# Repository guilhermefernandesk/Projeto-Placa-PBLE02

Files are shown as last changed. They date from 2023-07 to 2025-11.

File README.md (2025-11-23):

# Projeto-Placa-PBLE02
O projeto consiste na montagem de uma placa realizada por alunos da unifei. Bem como suas correções necessárias e simulação de uma aplicação via software na linguagem C.

## Autores:
<ul>
  <li> Eric Makiya Lazanha </li>
  <li> Guilherme Fernandes de Oliveira </li>
  <li> João Luiz de Miranda Cilli </li>
  <li> João Roberto da Silva Couto </li>
</ul>

## Imagens:
  PQDB
  PQDB2

## Vídeo apresentação do projeto:
https://drive.google.com/file/d/1amIkBEUgF5RGjeDBrGX1CGrTWx1kXM-I/view?usp=sharing

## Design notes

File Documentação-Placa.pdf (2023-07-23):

## Universidade Federal de Itajubá - UNIFEI

## PBLE02

## Board Bring-up e Validação de Protótipos Eletrônicos

Documentação do projeto

Grupo 01

Data

11/07/2023

## Sumário

IDENTIFICAÇÃO

Nome | Função | Matrícula
Eric Makiya Lazanha | Documentação | 2022004565
Guilherme Fernandes de Oliveira | Hardware | 2021005067
João Luiz de Miranda Cilli | Software | 2022003942
João Roberto da Silva Couto | Hardware | 2018000944

INTRODUÇÃO

Este documento tem como objetivo analisar os erros e fazer as mudanças necessárias para o funcionamento do projeto eletrônico desenvolvido pelo grupo 01 da disciplina Co-Design de Produtos Eletrônicos (PBLE01). Aqui encontram-se registrados os requisitos do hardware, com seus esquemas elétricos e layout de placa comentados de acordo com as modificações requeridas. Além disso, este documento apresenta diagramas para facilitar a compreensão da programação utilizada no projeto.

REQUISITOS DE DESENVOLVIMENTO

Divisões dos requisitos | Requisitos
Requisitos de alimentação | Suportar tensão de entrada na faixa de 7V a 12V em corrente contínua.

Empregar um conector de alimentação do tipo Jack J4.

Empregar proteção contra tensão reversa (opcional).

Empregar um regulador linear com saída de 5V.

Empregar um diodo emissor de luz para sinalizar a

presença de alimentação na placa.

Requisitos de

processamento

Empregar microcontrolador PIC18F4550 como unidade

de processamento e controle.

Possuir uma barra de pinos compatível com o padrão de

gravação ICSP para o microcontrolador empregado.

Possuir uma chave táctil para reiniciar a operação do

microcontrolador.

Requisitos de interações

com o usuário

Possuir um teclado numérico de cinco (5) teclas

confeccionado a partir de chaves tácteis.

Possuir um visor de 16x2 caracteres da família JHD62A,

com luminosidade a ser controlada por meio de

potenciômetro.

Possuir conjunto de, pelo menos, quatro (4) diodos

emissores de luz (LED) a partir do qual seja possível

sinalizar estados diversos de operação da unidade de

processamento e controle.

Possuir um potenciômetro (tripot) com o qual permitir a

entrada de valores contínuos por parte dos usuários.

Requisitos de periféricos e

expansão

Empregar um relógio de tempo real da família MCP7940.

Possuir uma barra de expansão que contemple os sinais

de referência e de alimentação da placa e quatro entradas

analógicas a formarem dois pares de entradas analógicas

diferenciais. Tais pares devem ser condicionados de

forma a se gerar níveis entre 0V e 3V a serem

disponibilizados ao microcontrolador empregado.

Possuir uma saída analógica formada por sinal em

modulação PWM.

Possuir uma barra de expansão de sinais que contemple

os sinais de referência (terra) e de alimentação do circuito

assim como os demais pinos não utilizados do

microcontrolador.

Requisitos adicionais

Empregar um conversor USB-serial da família MCP2200

que permita comunicação | serial | com | a placa

desenvolvida.

CIRCUITO

Para a melhor organização do esquemático, foram criados sub-circuitos, unidos por meio de rótulos hierárquicos. Os 4 sub circuitos são: Alimentação, Operação, Periféricos e Expansão, Interação com o usuário, assim como mostra a figura abaixo:

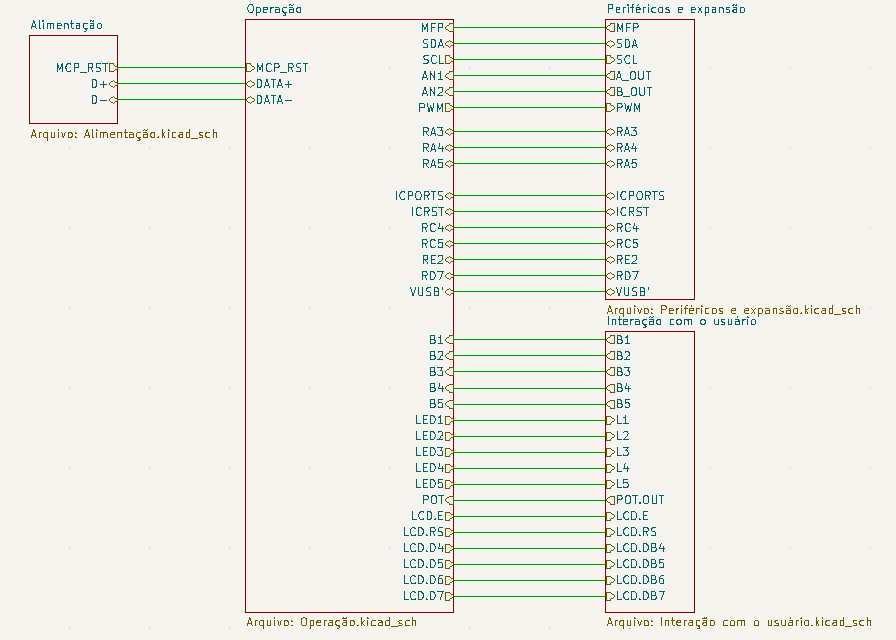
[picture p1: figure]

Figura 1 Blocos funcionais

CORREÇÕES DE HARDWARE
CIRCUITO DE OPERAÇÕES

Mudanças para o funcionamento do sub-circuito de Alimentação.

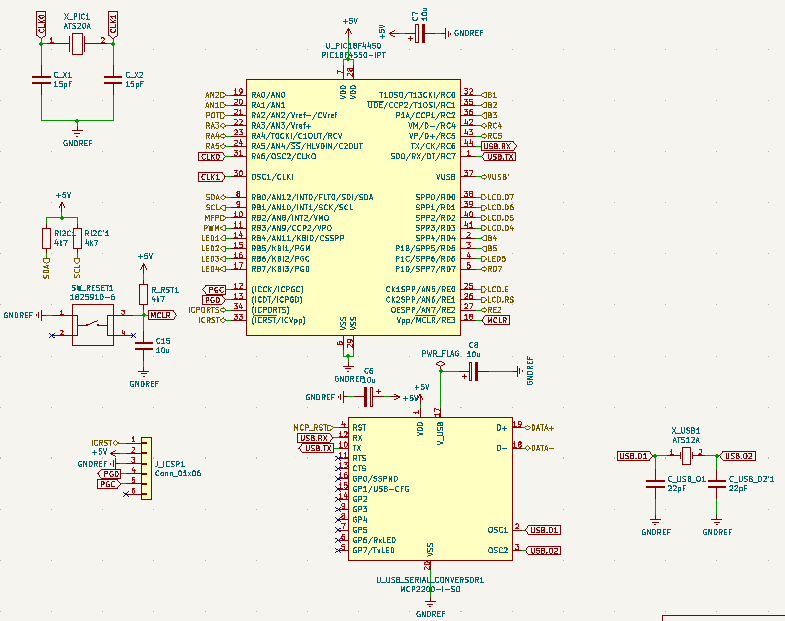
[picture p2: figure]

Figura 2 Sub-circuito de Alimentação completo corrigido

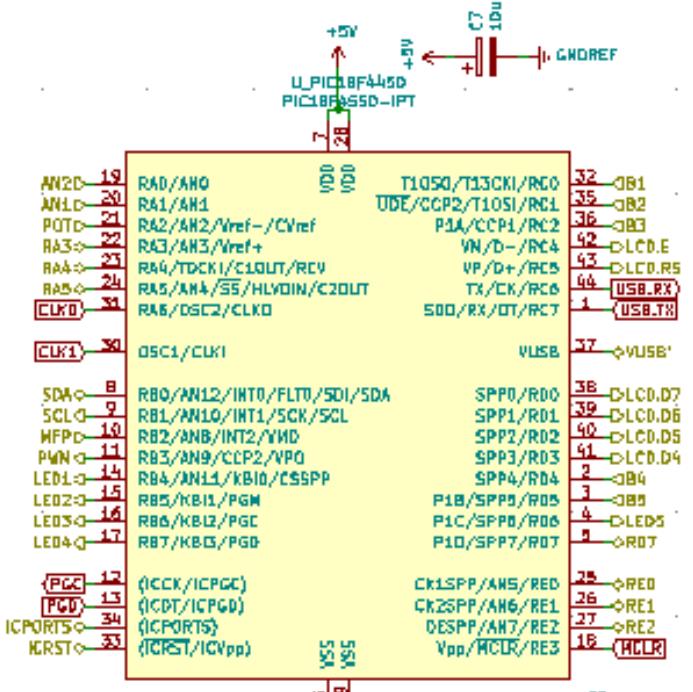
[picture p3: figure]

Figura 3 PIC18F4550 sem as alterações

O PGC e PGD não foram ligados aos pinos recomendados pelo fabricante, a recomendação é utilizar o PGC ligado ao pino 16 e o PGD ao pino 17. Como eles foram conectados a pinos diferentes algumas mudanças foram necessárias.

Tabela 1 informações da página 313 do datasheet do pic18f4550

Dessa forma, foi necessário fazer alterações envolvendo os pinos 18 e 33, o 18 (MCLR), originalmente ia para o pino 1 do conector de gravação do PICkit (PPTC061LFBN-RC), foi conectado ao botão de reset e o 33 (ICRST), que estava no sétimo pino de expansão, foi direcionado ao lugar anteriormente ocupado pelo MCLR no pino 1 do conector de gravação do PICkit. O MCLR atuava como um pino secundário (legacy), foi preciso passar para um pino com prioridade ICRST (dedicated).

O pino 18 (MCLR) do PIC18F4550 foi cortado de sua trilha original e passa direto para o botão de reset.

Observação: Reset deve ficar em nível lógico alto.

Figura 4 Esquemático antes

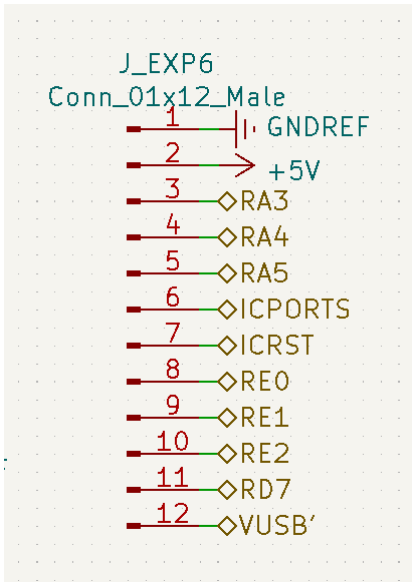
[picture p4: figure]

Figura 5 Pino de expansão antes

Pino 33 (ICRST) foi direcionado ao lugar anteriormente ocupado pelo MCLR no PPTC061LFBN-RC

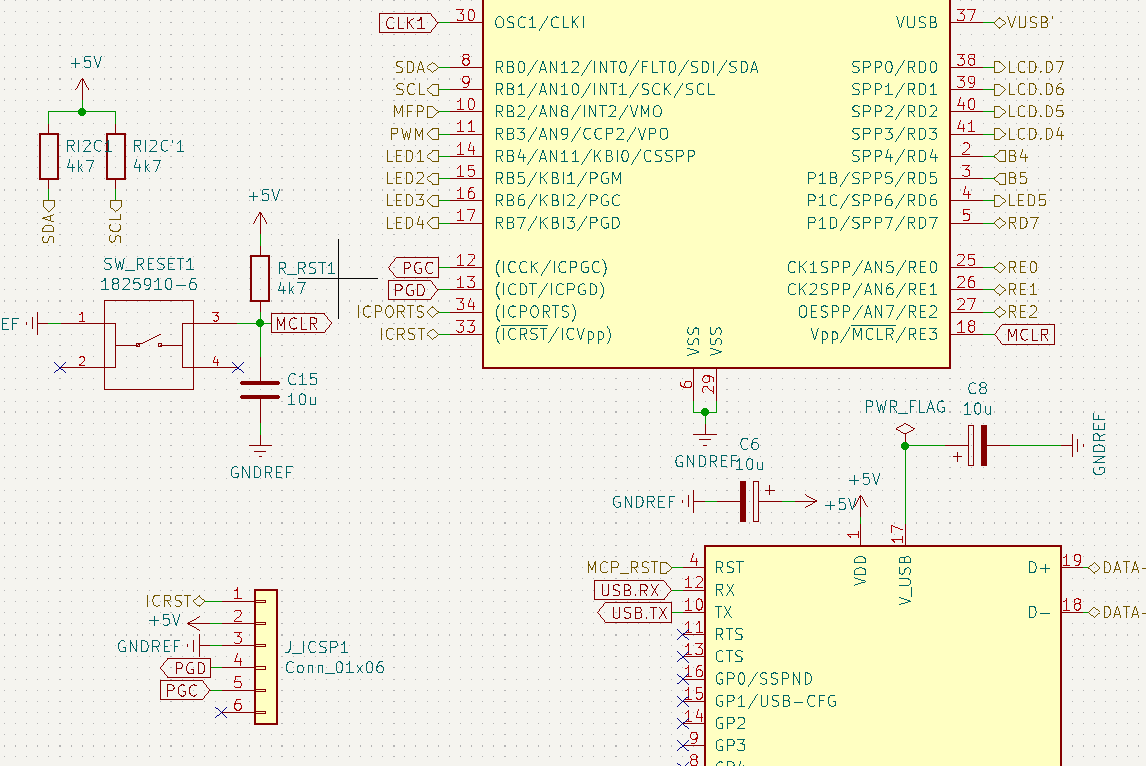
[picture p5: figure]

Figura 6 Correção ICRST e MCLR

Pino 33 (ICRST) foi retirado do header de expansão.

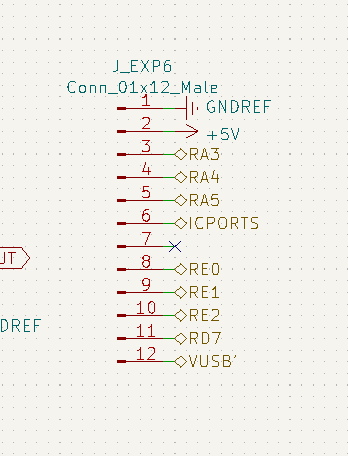
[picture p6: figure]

Figura 7 Pino de expansão depois

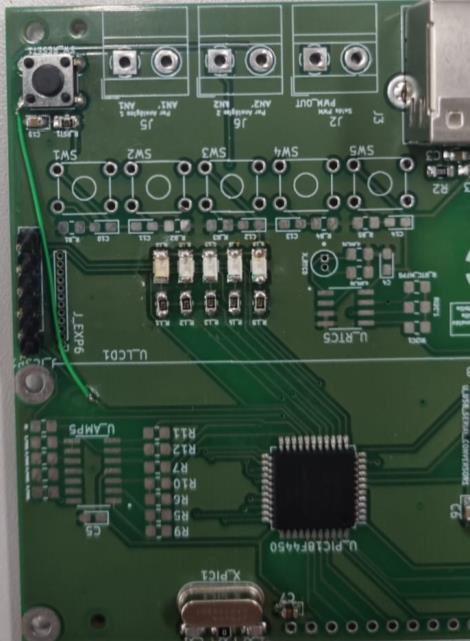
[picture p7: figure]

Figura 8 Redirecionamento do pino 18

O pino 33 (ICRST) foi ligado ao PPTC061LFBN-RC onde estava o MCLR.

Figura 9 Ajuste do ICRST

O pino 15 (LED2) do display estava no GND foi necessário colocá-lo no VCC. Pois a iluminação estava baixa.

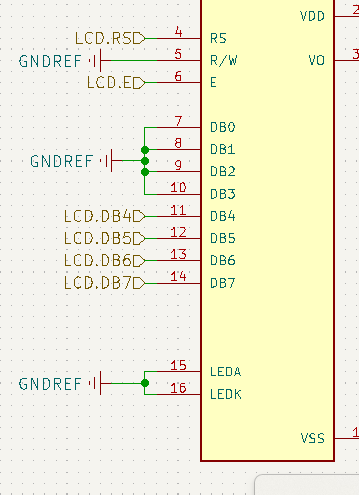
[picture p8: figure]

Figura 10 Esquemático antes

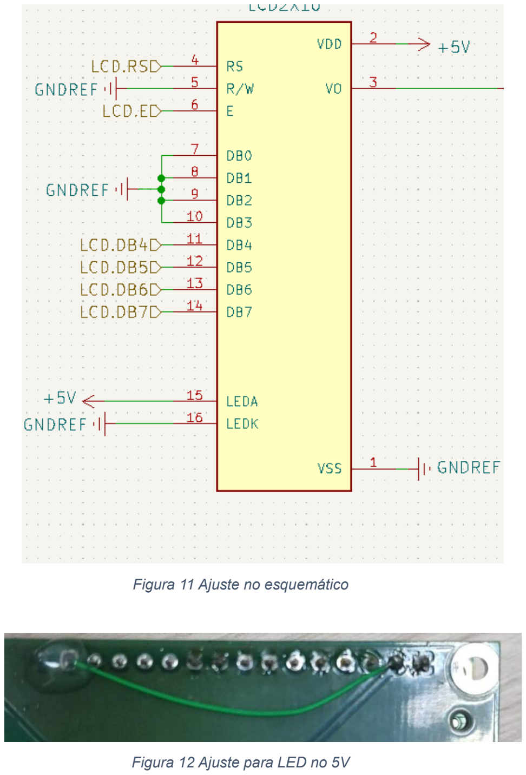
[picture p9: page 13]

Figura 11 Ajuste no esquemático

Figura 12 Ajuste para LED no 5V

Os pinos 42 (RC4) e 43 (RC5) que fazem a ligação com os displays não podem atuar como saídas, portanto tiveram que ser alterados. Dessa forma, optou-se por utilizar os pinos de expansão, trocando o pino 42 pelo 25 (8 da expansão) e o pino 43 pelo 26 (9 da expansão).

Figura 13 Esquemático antes

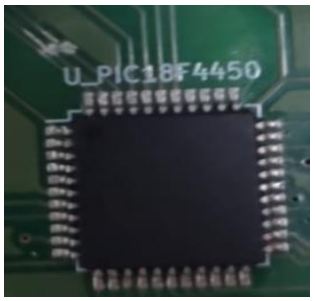
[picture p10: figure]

Figura 14 Corte das trilhas dos pinos 42 e 43

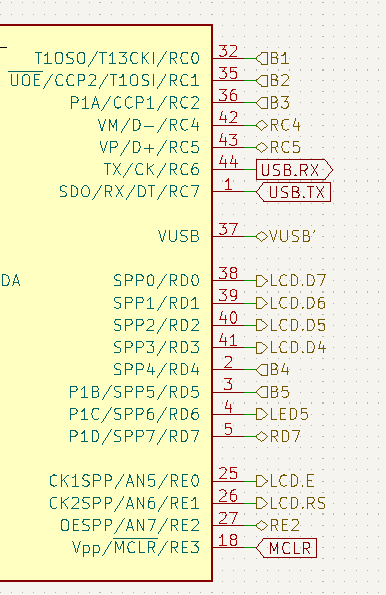
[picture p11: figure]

Figura 15 Esquemático corrigido

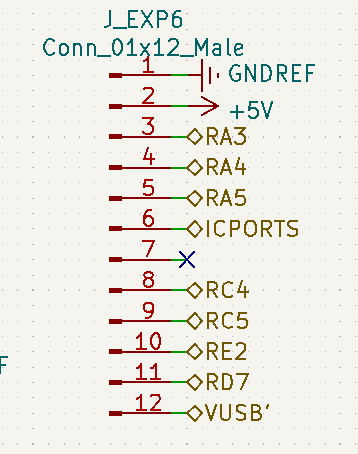
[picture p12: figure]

Figura 16 LEDs nos pinos de expansão 8 e 9

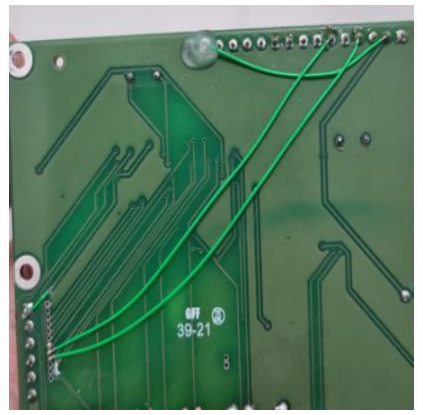
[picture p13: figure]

Figura 17 justes para os pinos de expansão

Foram trocados os capacitores do micro para um capacitor de 18pF em paralelo com um capacitor de 18pF (18pF em série com um resistor de 0 ohms), o datasheet recomendava dois capacitores de 15pF em paralelo.

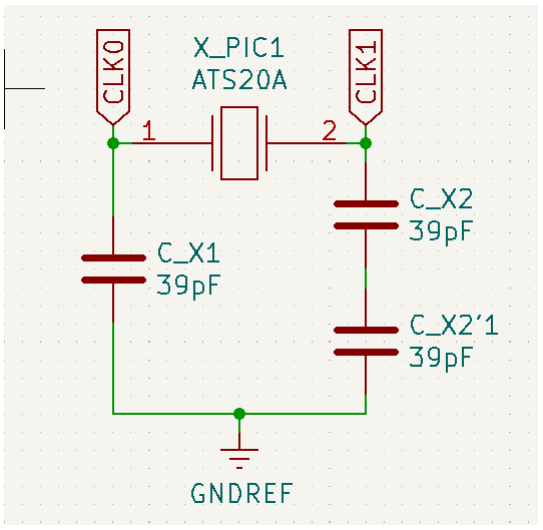
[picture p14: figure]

Figura 18 Esquemático cristal antes

Figura 19 Ajuste para capacitores de 15pF em paralelo

Foram trocados os capacitores do usb para um capacitor de 22pF em paralelo com um capacitor de 22pF (22pF em série com um resistor de 0 ohms), conforme o datasheet recomenda.

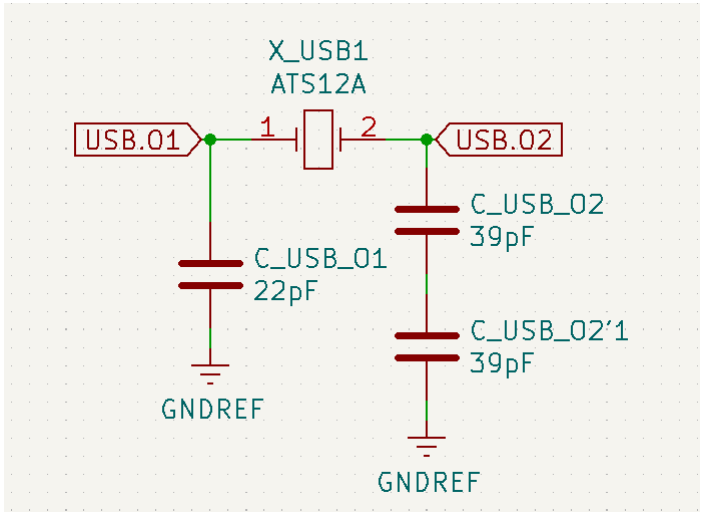
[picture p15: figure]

Figura 20 Capacitores do usb antes

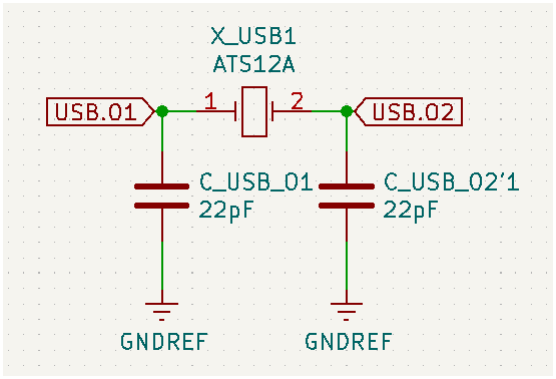
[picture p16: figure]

Figura 21 Capacitores usb corrigidos

CIRCUITO DE INTERAÇÃO COM O USUÁRIO

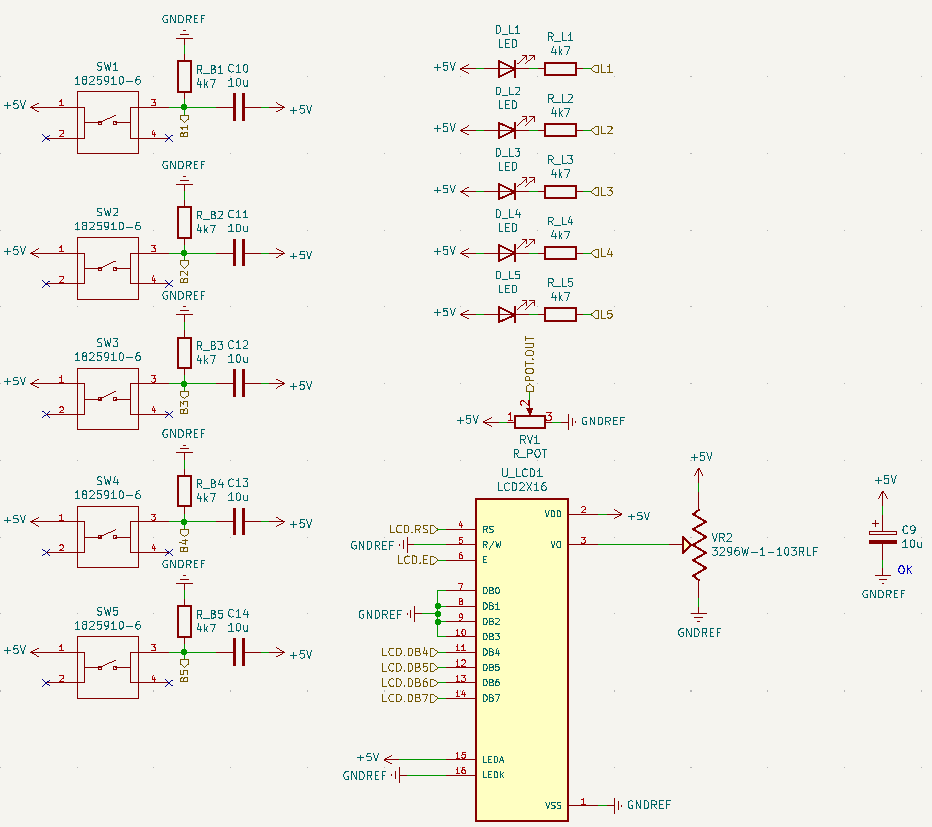
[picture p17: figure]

Figura 22 Sub-circuito de Interação com o usuário completo corrigido

Todos os resistores de 330 Ohms foral substituídos por resistores de 4k7 Ohms para ajuste da intensidade de brilho.

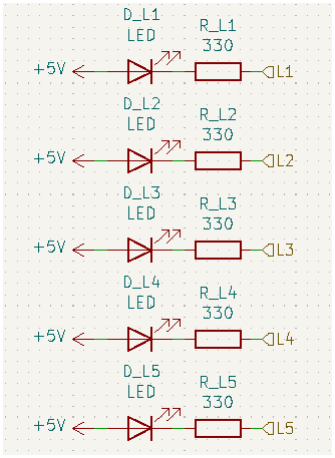
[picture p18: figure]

Figura 23 Esquemático antes da correção

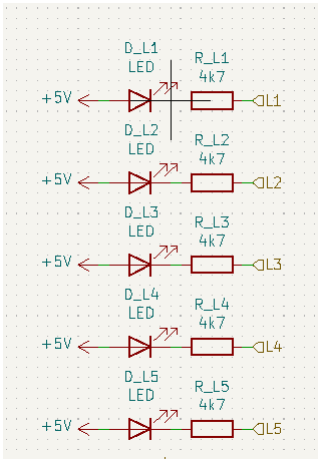
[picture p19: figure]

Figura 24 Resistores corrigidos

Foi necessário ajustar o header para 90° para o encaixe simultâneo do PICkit com o display. Anteriormente o display ficava sobre o PICkit, impedindo o encaixe.

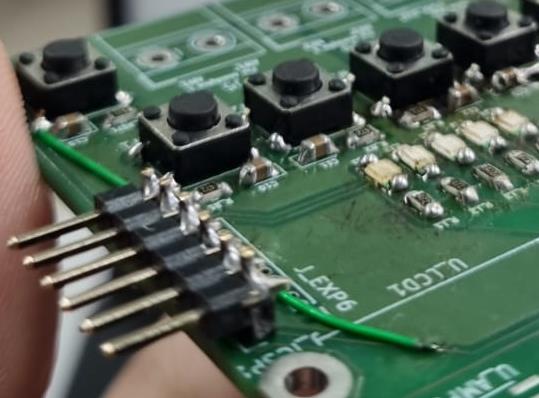
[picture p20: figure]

Figura 25 Header 90°

Figura 26 PICkit e display

PCB

Figura 27 PCB completa corrigida

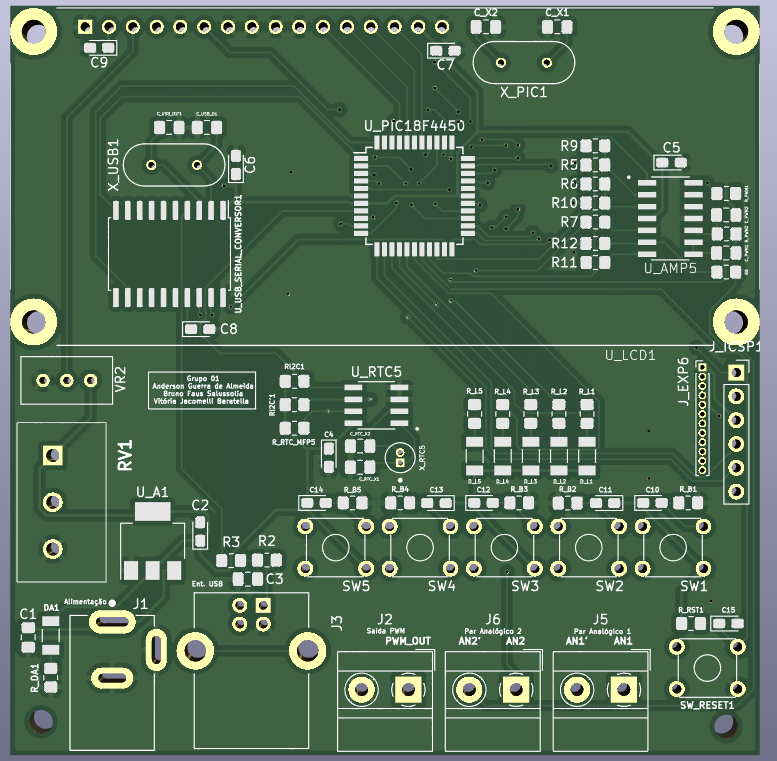
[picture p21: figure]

Figura 28 Visão frontal 3D

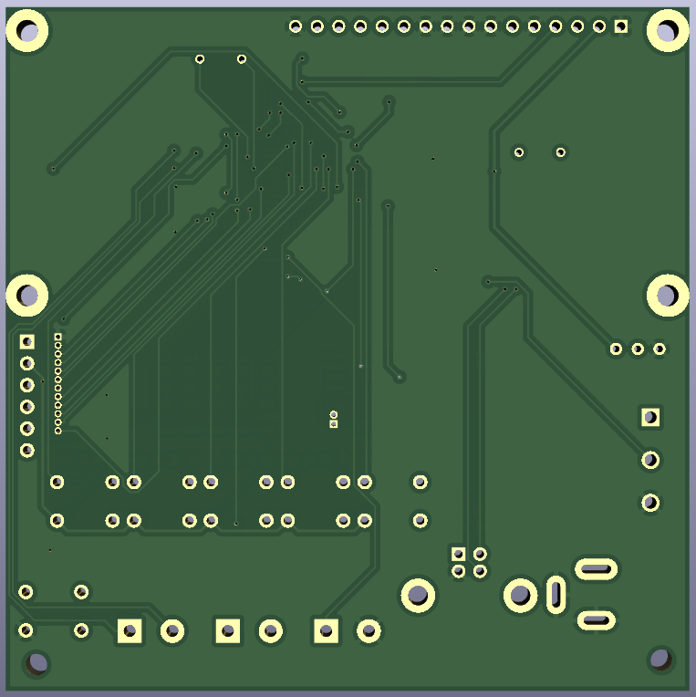
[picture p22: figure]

Figura 29 Visão de trás

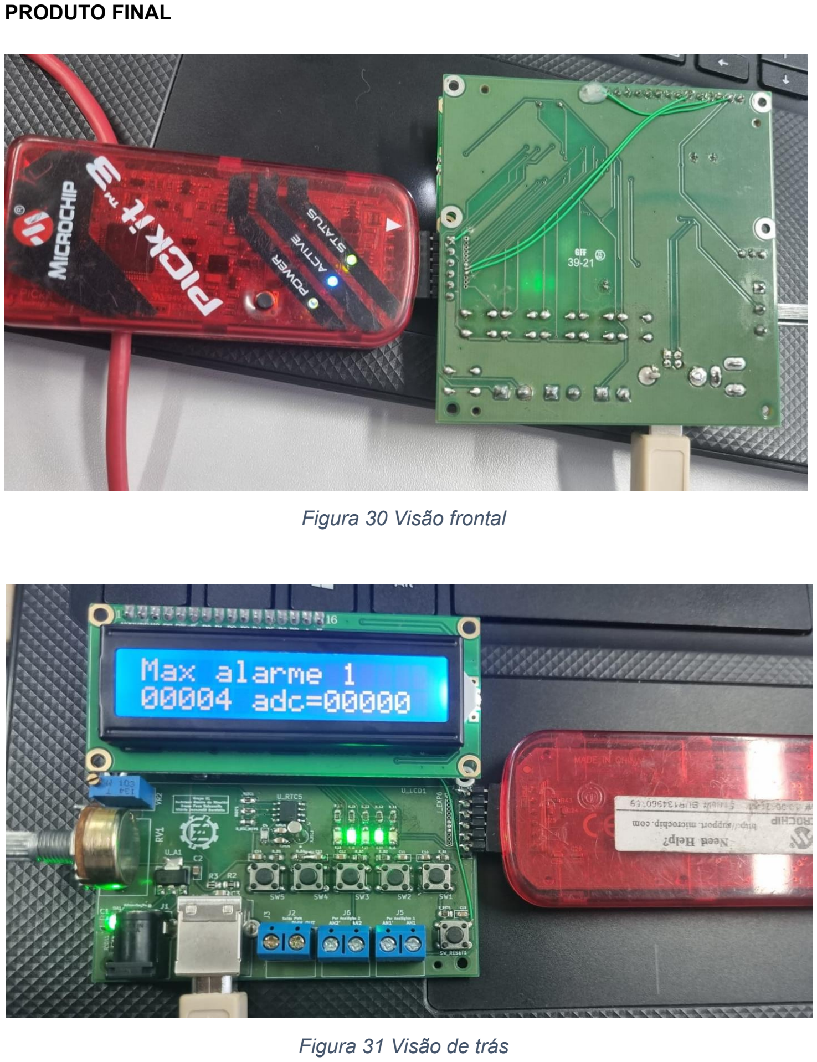
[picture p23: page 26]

PRODUTO FINAL

Figura 30 Visão frontal

Figura 31 Visão de trás

DIAGRAMAS

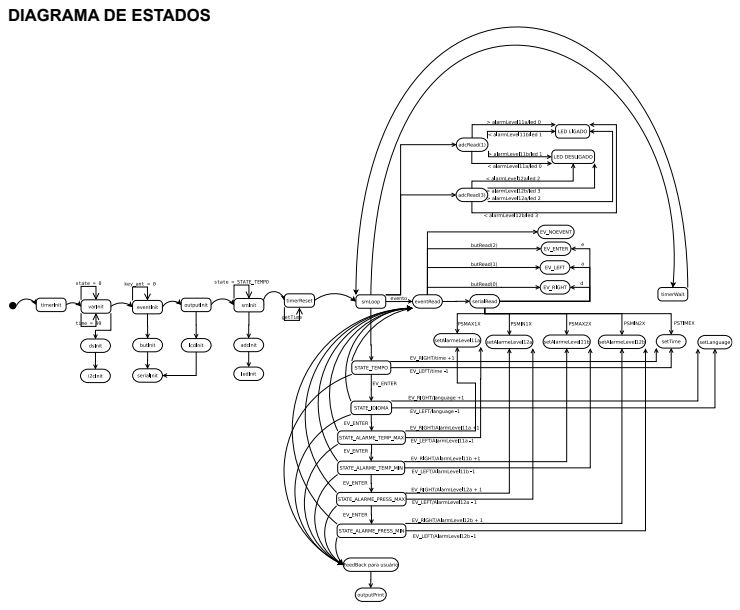
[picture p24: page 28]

DIAGRAMA DE ESTADOS

BIBLIOGRAFIA

[1] LD1117DT50TR. Datasheet: https://br.mouser.com/datasheet/2/389/cd00000544-1795431.pdf (https://br.mouser.com/datasheet/2/389/cd00000544-1795431.pdf)
[2] PIC18F4550-I/PT. Datasheet: https://www.mouser.com/datasheet/2/268/39632e-48732.pdf (https://www.mouser.com/datasheet/2/268/39632e-48732.pdf)
[3] LD1117DT50TR. Datasheet: https://br.mouser.com/datasheet/2/389/cd00000544-1795431.pdf (https://br.mouser.com/datasheet/2/389/cd00000544-1795431.pdf)
[4] MCP7940N-I/SN. Datasheet: https://br.mouser.com/datasheet/2/268/25010A-71550.pdf
[5] MCP2200-I/SO. Datasheet: https://www.maxwell.vrac.puc-rio.br/11319/11319_8.PDF
[6] PJ-002A. Datasheet: https://br.mouser.com/datasheet/2/670/pj_002a-1778764.pdf
[7] LTST-C150GKT. Datasheet:

https://datasheet.datasheetarchive.com/originals/dk/DKDS-9/177278.pdf

[8] PPTC061LFBN-RC. Datasheet: https://www.digikey.com/en/products/detail/sullins-

connector- (https://www.digikey.com/en/products/detail/sullins-connector-solutions/PPTC061LFBN-RC/810145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) solutions/PPTC061LFBN-

RC/810145?utm_campaign=buynow&utm_medium=aggregator&WT.z_cid=ref_findchips_standard

&utm_sou (https://www.digikey.com/en/products/detail/sullins-connector-solutions/PPTC061LFBN-RC/810145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) rce=findchips (https://www.digikey.com/en/products/detail/sullins-connector-solutions/PPTC061LFBN-RC/810145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)

[9] 1825910-6. Datasheet:

https://www.te.com/commerce/DocumentDelivery/DDEController?Action=srchrtrv&Doc

Nm=1825 (https://www.te.com/commerce/DocumentDelivery/DDEController?Action=srchrtrv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) 910&DocType=Customer+Drawing&DocLang=English&PartCntxt=1825910-

6&DocFormat=pdf (https://www.te.com/commerce/DocumentDelivery/DDEController?Action=srchrtrv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)
[10] LM358DG / LM324DG. Datasheet:

https://br.mouser.com/datasheet/2/308/1/LM324_D-2314880.pdf
[11] JHD162A. Datasheet:

https://www.alldatasheet.com/datasheet-

pdf/pdf/127934/ETC1/JHD162A.html (https://www.alldatasheet.com/datasheet-pdf/pdf/127934/ETC1/JHD162A.html)
[12] P160KN-0QC15B100K. Datasheet: https://br.mouser.com/datasheet/2/414/P160-1545428.pdf (https://br.mouser.com/datasheet/2/414/P160-1545428.pdf)
[13] 897-43-004-90-000000. Datasheet: https://www.mouser.com/datasheet/2/273/148-259756.pdf (https://www.mouser.com/datasheet/2/273/148-259756.pdf)
[14] F931C106KAA. Datasheet: https://br.mouser.com/datasheet/2/40/f93-776559.pdf
[15] AB38T-32. Datasheet: https://html.alldatasheet.com/htmlpdf/563572/ABRACON/AB38T-32-

ATS20A 768KHZ/610/2/AB38T-32-768KHZ.html (https://html.alldatasheet.com/html-pdf/563572/ABRACON/AB38T-32-ATS20A%20768KHZ/610/2/AB38T-32-768KHZ.html)

[16] ATS20A. Datasheet: https://br.mouser.com/datasheet/2/96/008-0309-0-786275.pdf
[17] 1N4001RLG. Datasheet: https://dir.heisener.com/specification-pdf/en/1N4001RLG.pdf
[18] 1N5819HW-7. Datasheet: https://br.mouser.com/datasheet/2/115/ds30217-71027.pdf
[19] Henrique Mattede. Mundo da Elétrica. Disponível em: <

https://www.mundodaele- (https://www.mundodaeletrica.com.br/aprenda-como-calcular-resistor-para-led/) trica.com.br/aprenda-como-calcular-resistor-para-

led/ (https://www.mundodaeletrica.com.br/aprenda-como-calcular-resistor-para-led/) >. Acesso em 20 de maio de 2021.
[20] Ronieri Rezende. Embarcados. Disponível em: <

https://www.embarcados.com.br/interface-gra-fica-para-uart/ >. Acesso em 8 de ago. de

2021

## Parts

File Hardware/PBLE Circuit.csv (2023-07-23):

Source: | C:\Users\ericl\OneDrive\Área de Trabalho\Faculdade\PLBE02\PBLE Circuit-20230606T190801Z-001\PBLE Circuit\PBLE Circuit.kicad_sch
Date: | 06/06/2023 16:24:42
Tool: | Eeschema (6.0.4)
Generator: | C:\Program Files\KiCad\6.0\bin\scripting\plugins/bom_csv_grouped_by_value.py
Component Count: | 82
Individual Components:
Item | Qty | Reference(s) | Value | LibPart | Footprint | Datasheet | Comment | Configuration_Pole-Throw | Contact_Current_Rating | EU_RoHS_Compliance | MANUFACTURER | MAXIMUM_PACKAGE_HIEGHT | PARTREV | STANDARD
 |  | C1 | 100n | Device:C | Capacitor_SMD:C_0805_2012Metric_Pad1.18x1.45mm_HandSolder | ~
 |  | C2 | 10u | PBLE-Circuit-rescue:CP-Device | Capacitor_Tantalum_SMD:CP_EIA-2012-15_AVX-P_Pad1.30x1.05mm_HandSolder
 |  | C3 | 100nF | Device:C | Capacitor_SMD:C_0805_2012Metric_Pad1.18x1.45mm_HandSolder | ~
 |  | C4 | 10u | PBLE-Circuit-rescue:CP-Device | Capacitor_Tantalum_SMD:CP_EIA-2012-15_AVX-P_Pad1.30x1.05mm_HandSolder
 |  | C5 | 10u | PBLE-Circuit-rescue:CP-Device | Capacitor_Tantalum_SMD:CP_EIA-2012-15_AVX-P_Pad1.30x1.05mm_HandSolder
 |  | C6 | 10u | PBLE-Circuit-rescue:CP-Device | Capacitor_Tantalum_SMD:CP_EIA-2012-15_AVX-P_Pad1.30x1.05mm_HandSolder
 |  | C7 | 10u | PBLE-Circuit-rescue:CP-Device | Capacitor_Tantalum_SMD:CP_EIA-2012-15_AVX-P_Pad1.30x1.05mm_HandSolder
 |  | C8 | 10u | PBLE-Circuit-rescue:CP-Device | Capacitor_Tantalum_SMD:CP_EIA-2012-15_AVX-P_Pad1.30x1.05mm_HandSolder
 |  | C9 | 10u | PBLE-Circuit-rescue:CP-Device | Capacitor_Tantalum_SMD:CP_EIA-2012-15_AVX-P_Pad1.30x1.05mm_HandSolder
 |  | C10 | 10u | Device:C | Capacitor_Tantalum_SMD:CP_EIA-2012-15_AVX-P_Pad1.30x1.05mm_HandSolder | ~
 |  | C11 | 10u | Device:C | Capacitor_Tantalum_SMD:CP_EIA-2012-15_AVX-P_Pad1.30x1.05mm_HandSolder | ~
 |  | C12 | 10u | Device:C | Capacitor_Tantalum_SMD:CP_EIA-2012-15_AVX-P_Pad1.30x1.05mm_HandSolder | ~
 |  | C13 | 10u | Device:C | Capacitor_Tantalum_SMD:CP_EIA-2012-15_AVX-P_Pad1.30x1.05mm_HandSolder | ~
 |  | C14 | 10u | Device:C | Capacitor_Tantalum_SMD:CP_EIA-2012-15_AVX-P_Pad1.30x1.05mm_HandSolder | ~
 |  | C15 | 10u | Device:C | Capacitor_Tantalum_SMD:CP_EIA-2012-15_AVX-P_Pad1.30x1.05mm_HandSolder | ~
 |  | C_PWM1 | 20p | Device:C | Capacitor_SMD:C_0805_2012Metric_Pad1.18x1.45mm_HandSolder | ~
 |  | C_PWM2 | 39p | Device:C | Capacitor_SMD:C_0805_2012Metric_Pad1.18x1.45mm_HandSolder | ~
 |  | C_RTC_X1 | 22pF | Device:C | Capacitor_SMD:C_0805_2012Metric_Pad1.18x1.45mm_HandSolder | ~
 |  | C_RTC_X2 | 22pF | Device:C | Capacitor_SMD:C_0805_2012Metric_Pad1.18x1.45mm_HandSolder | ~
 |  | C_USB_O1 | 22pF | Device:C | Capacitor_SMD:C_0805_2012Metric_Pad1.18x1.45mm_HandSolder | ~
 |  | C_USB_O2 | 39pF | Device:C | Capacitor_SMD:C_0805_2012Metric_Pad1.18x1.45mm_HandSolder | ~
 |  | C_USB_O2'1 | 39pF | Device:C | Capacitor_SMD:C_0805_2012Metric_Pad1.18x1.45mm_HandSolder | ~
 |  | C_X1 | 39pF | Device:C | Capacitor_SMD:C_0805_2012Metric_Pad1.18x1.45mm_HandSolder | ~
 |  | C_X2 | 39pF | Device:C | Capacitor_SMD:C_0805_2012Metric_Pad1.18x1.45mm_HandSolder | ~
 |  | C_X2'1 | 39pF | Device:C | Capacitor_SMD:C_0805_2012Metric_Pad1.18x1.45mm_HandSolder | ~
 |  | D_L1 | LED | Device:LED | Biblioteca PCB:LTST-C150GKT | ~
 |  | D_L2 | LED | Device:LED | Biblioteca PCB:LTST-C150GKT | ~
 |  | D_L3 | LED | Device:LED | Biblioteca PCB:LTST-C150GKT | ~
 |  | D_L4 | LED | Device:LED | Biblioteca PCB:LTST-C150GKT | ~
 |  | D_L5 | LED | Device:LED | Biblioteca PCB:LTST-C150GKT | ~
 |  | DA1 | LED | Device:LED | Biblioteca PCB:LTST-C150GKT | ~
 |  | J1 | PJ-002A | PBLE Library:PJ-002A | Biblioteca PCB:CUI_PJ-002A |  |  |  |  |  | CUI INC |  |  | Manufacturer recommendations
 |  | J2 | Screw_Terminal_01x02 | Connector:Screw_Terminal_01x02 | TerminalBlock_MetzConnect:TerminalBlock_MetzConnect_Type011_RT05502HBWC_1x02_P5.00mm_Horizontal | ~
 |  | J3 | USB_B | Connector:USB_B | Connector_USB:USB_B_Lumberg_2411_02_Horizontal | ~
 |  | J5 | Screw_Terminal_01x02 | Connector:Screw_Terminal_01x02 | TerminalBlock_MetzConnect:TerminalBlock_MetzConnect_Type011_RT05502HBWC_1x02_P5.00mm_Horizontal | ~
 |  | J6 | Screw_Terminal_01x02 | Connector:Screw_Terminal_01x02 | TerminalBlock_MetzConnect:TerminalBlock_MetzConnect_Type011_RT05502HBWC_1x02_P5.00mm_Horizontal | ~
 |  | J_EXP6 | Conn_01x12_Male | Connector:Conn_01x12_Male | Connector_PinHeader_1.00mm:PinHeader_1x12_P1.00mm_Vertical | ~
 |  | J_ICSP1 | Conn_01x06 | Connector_Generic:Conn_01x06 | Connector_PinSocket_2.54mm:PinSocket_1x06_P2.54mm_Vertical | ~
 |  | R2 | 10k | Device:R | Resistor_SMD:R_0805_2012Metric_Pad1.20x1.40mm_HandSolder | ~
 |  | R3 | 470 | Device:R | Resistor_SMD:R_0805_2012Metric_Pad1.20x1.40mm_HandSolder | ~
 |  | R5 | 10k | Device:R | Resistor_SMD:R_0805_2012Metric_Pad1.20x1.40mm_HandSolder | ~
 |  | R6 | 10k | Device:R | Resistor_SMD:R_0805_2012Metric_Pad1.20x1.40mm_HandSolder | ~
 |  | R7 | 10k | Device:R | Resistor_SMD:R_0805_2012Metric_Pad1.20x1.40mm_HandSolder | ~
 |  | R8 | 10k | Device:R | Resistor_SMD:R_0805_2012Metric_Pad1.20x1.40mm_HandSolder | ~
 |  | R9 | 2k4 | Device:R | Resistor_SMD:R_0805_2012Metric_Pad1.20x1.40mm_HandSolder | ~
 |  | R10 | 2k4 | Device:R | Resistor_SMD:R_0805_2012Metric_Pad1.20x1.40mm_HandSolder | ~
 |  | R11 | 2k4 | Device:R | Resistor_SMD:R_0805_2012Metric_Pad1.20x1.40mm_HandSolder | ~
 |  | R12 | 2k4 | Device:R | Resistor_SMD:R_0805_2012Metric_Pad1.20x1.40mm_HandSolder | ~
 |  | R_B1 | 4k7 | Device:R | Resistor_SMD:R_0805_2012Metric_Pad1.20x1.40mm_HandSolder | ~
 |  | R_B2 | 4k7 | Device:R | Resistor_SMD:R_0805_2012Metric_Pad1.20x1.40mm_HandSolder | ~
 |  | R_B3 | 4k7 | Device:R | Resistor_SMD:R_0805_2012Metric_Pad1.20x1.40mm_HandSolder | ~
 |  | R_B4 | 4k7 | Device:R | Resistor_SMD:R_0805_2012Metric_Pad1.20x1.40mm_HandSolder | ~
 |  | R_B5 | 4k7 | Device:R | Resistor_SMD:R_0805_2012Metric_Pad1.20x1.40mm_HandSolder | ~
 |  | R_DA1 | 330 | Device:R | Resistor_SMD:R_0805_2012Metric_Pad1.20x1.40mm_HandSolder | ~
 |  | R_L1 | 330 | Device:R | Resistor_SMD:R_0805_2012Metric_Pad1.20x1.40mm_HandSolder | ~
 |  | R_L2 | 330 | Device:R | Resistor_SMD:R_0805_2012Metric_Pad1.20x1.40mm_HandSolder | ~
 |  | R_L3 | 330 | Device:R | Resistor_SMD:R_0805_2012Metric_Pad1.20x1.40mm_HandSolder | ~
 |  | R_L4 | 330 | Device:R | Resistor_SMD:R_0805_2012Metric_Pad1.20x1.40mm_HandSolder | ~
 |  | R_L5 | 330 | Device:R | Resistor_SMD:R_0805_2012Metric_Pad1.20x1.40mm_HandSolder | ~
 |  | R_PWM1 | 20k | Device:R | Resistor_SMD:R_0805_2012Metric_Pad1.20x1.40mm_HandSolder | ~
 |  | R_PWM2 | 20k | Device:R | Resistor_SMD:R_0805_2012Metric_Pad1.20x1.40mm_HandSolder | ~
 |  | R_RST1 | 4k7 | Device:R | Resistor_SMD:R_0805_2012Metric_Pad1.20x1.40mm_HandSolder | ~
 |  | R_RTC_MFP5 | 10k | Device:R | Resistor_SMD:R_0805_2012Metric_Pad1.20x1.40mm_HandSolder | ~
 |  | RI2C1 | 4k7 | Device:R | Resistor_SMD:R_0805_2012Metric_Pad1.20x1.40mm_HandSolder | ~
 |  | RI2C'1 | 4k7 | Device:R | Resistor_SMD:R_0805_2012Metric_Pad1.20x1.40mm_HandSolder | ~
 |  | RV1 | R_POT | PBLE-Circuit-rescue:R_POT-Device | Biblioteca PCB:P160KN-0QC15B100K
 |  | SW1 | 1825910-6 | PBLE Library:1825910-6 | Button_Switch_THT:SW_TH_Tactile_Omron_B3F-10xx |  | 1825910-6 | Single Pole - Single Throw | 50 mA | Compliant
 |  | SW2 | 1825910-6 | PBLE Library:1825910-6 | Button_Switch_THT:SW_TH_Tactile_Omron_B3F-10xx |  | 1825910-6 | Single Pole - Single Throw | 50 mA | Compliant
 |  | SW3 | 1825910-6 | PBLE Library:1825910-6 | Button_Switch_THT:SW_TH_Tactile_Omron_B3F-10xx |  | 1825910-6 | Single Pole - Single Throw | 50 mA | Compliant
 |  | SW4 | 1825910-6 | PBLE Library:1825910-6 | Button_Switch_THT:SW_TH_Tactile_Omron_B3F-10xx |  | 1825910-6 | Single Pole - Single Throw | 50 mA | Compliant
 |  | SW5 | 1825910-6 | PBLE Library:1825910-6 | Button_Switch_THT:SW_TH_Tactile_Omron_B3F-10xx |  | 1825910-6 | Single Pole - Single Throw | 50 mA | Compliant
 |  | SW_RESET1 | 1825910-6 | PBLE Library:1825910-6 | Button_Switch_THT:SW_TH_Tactile_Omron_B3F-10xx |  | 1825910-6 | Single Pole - Single Throw | 50 mA | Compliant
 |  | U_A1 | LD1117S50TR_SOT223 | Regulator_Linear:LD1117S50TR_SOT223 | Package_TO_SOT_SMD:SOT-223-3_TabPin2 | http://www.st.com/st-web-ui/static/active/en/resource/technical/document/datasheet/CD00000544.pdf
 |  | U_AMP5 | LM324DG | PBLE Library:LM324DG | Biblioteca PCB:LM324DG
 |  | U_LCD1 | LCD2X16 | PBLE Library:LCD2X16 | Biblioteca PCB:JHD162A |  |  |  |  |  | Microelektronika | 10mm | 0 | Manufacturer Recommendations
 |  | U_PIC18F4450 | PIC18F4550-IPT | MCU_Microchip_PIC18:PIC18F4550-IPT | Package_QFP:TQFP-44_10x10mm_P0.8mm | http://ww1.microchip.com/downloads/en/DeviceDoc/39760d.pdf
 |  | U_RTC5 | MCP7940N-xSN | PBLE-Circuit-rescue:MCP7940N-xSN-Timer | Biblioteca PCB:MCP7940N | http://ww1.microchip.com/downloads/en/DeviceDoc/20005010F.pdf
 |  | U_USB_SERIAL_CONVERSOR1 | MCP2200-I-SO | Interface_USB:MCP2200-I-SO | Package_SO:SOIC-20W_7.5x12.8mm_P1.27mm | http://ww1.microchip.com/downloads/en/DeviceDoc/200022228D.pdf
 |  | VR2 | 3296W-1-103RLF | PBLE Library:3296W-1-103RLF | Potentiometer_THT:Potentiometer_Bourns_3296W_Vertical |  |  |  |  |  | Bourns |  | 05/16 | Manufacturer Recommendation
 |  | X_PIC1 | ATS20A | PBLE Library:ATS20A | Biblioteca PCB:ATS20A
 |  | X_RTC5 | AB38T-32.768KHZ | PBLE Library:AB38T-32.768KHZ | Biblioteca PCB:AB38T |  |  |  |  |  | Abracon Corparation |  | 12.29.14 | IPC-7251
 |  | X_USB1 | ATS12A | PBLE Library:ATS12A | Biblioteca PCB:ATS12A
Collated Components:
Item | Qty | Reference(s) | Value | LibPart | Footprint | Datasheet | Comment | Configuration_Pole-Throw | Contact_Current_Rating | EU_RoHS_Compliance | MANUFACTURER | MAXIMUM_PACKAGE_HIEGHT | PARTREV | STANDARD
1 | 1 | C1 | 100n | Device:C | Capacitor_SMD:C_0805_2012Metric_Pad1.18x1.45mm_HandSolder | ~
2 | 7 | C2, C4, C5, C6, C7, C8, C9 | 10u | PBLE-Circuit-rescue:CP-Device | Capacitor_Tantalum_SMD:CP_EIA-2012-15_AVX-P_Pad1.30x1.05mm_HandSolder
3 | 1 | C3 | 100nF | Device:C | Capacitor_SMD:C_0805_2012Metric_Pad1.18x1.45mm_HandSolder | ~
4 | 6 | C10, C11, C12, C13, C14, C15 | 10u | Device:C | Capacitor_Tantalum_SMD:CP_EIA-2012-15_AVX-P_Pad1.30x1.05mm_HandSolder | ~
5 | 1 | C_PWM1 | 20p | Device:C | Capacitor_SMD:C_0805_2012Metric_Pad1.18x1.45mm_HandSolder | ~
6 | 1 | C_PWM2 | 39p | Device:C | Capacitor_SMD:C_0805_2012Metric_Pad1.18x1.45mm_HandSolder | ~
7 | 3 | C_RTC_X1, C_RTC_X2, C_USB_O1 | 22pF | Device:C | Capacitor_SMD:C_0805_2012Metric_Pad1.18x1.45mm_HandSolder | ~
8 | 5 | C_USB_O2, C_USB_O2'1, C_X1, C_X2, C_X2'1 | 39pF | Device:C | Capacitor_SMD:C_0805_2012Metric_Pad1.18x1.45mm_HandSolder | ~
9 | 6 | D_L1, D_L2, D_L3, D_L4, D_L5, DA1 | LED | Device:LED | Biblioteca PCB:LTST-C150GKT | ~
10 | 1 | J1 | PJ-002A | PBLE Library:PJ-002A | Biblioteca PCB:CUI_PJ-002A |  |  |  |  |  | CUI INC |  |  | Manufacturer recommendations
11 | 3 | J2, J5, J6 | Screw_Terminal_01x02 | Connector:Screw_Terminal_01x02 | TerminalBlock_MetzConnect:TerminalBlock_MetzConnect_Type011_RT05502HBWC_1x02_P5.00mm_Horizontal | ~
12 | 1 | J3 | USB_B | Connector:USB_B | Connector_USB:USB_B_Lumberg_2411_02_Horizontal | ~
13 | 1 | J_EXP6 | Conn_01x12_Male | Connector:Conn_01x12_Male | Connector_PinHeader_1.00mm:PinHeader_1x12_P1.00mm_Vertical | ~
14 | 1 | J_ICSP1 | Conn_01x06 | Connector_Generic:Conn_01x06 | Connector_PinSocket_2.54mm:PinSocket_1x06_P2.54mm_Vertical | ~
15 | 6 | R2, R5, R6, R7, R8, R_RTC_MFP5 | 10k | Device:R | Resistor_SMD:R_0805_2012Metric_Pad1.20x1.40mm_HandSolder | ~
16 | 1 | R3 | 470 | Device:R | Resistor_SMD:R_0805_2012Metric_Pad1.20x1.40mm_HandSolder | ~
17 | 4 | R9, R10, R11, R12 | 2k4 | Device:R | Resistor_SMD:R_0805_2012Metric_Pad1.20x1.40mm_HandSolder | ~
18 | 8 | R_B1, R_B2, R_B3, R_B4, R_B5, R_RST1, RI2C1, RI2C'1 | 4k7 | Device:R | Resistor_SMD:R_0805_2012Metric_Pad1.20x1.40mm_HandSolder | ~
19 | 6 | R_DA1, R_L1, R_L2, R_L3, R_L4, R_L5 | 330 | Device:R | Resistor_SMD:R_0805_2012Metric_Pad1.20x1.40mm_HandSolder | ~
20 | 2 | R_PWM1, R_PWM2 | 20k | Device:R | Resistor_SMD:R_0805_2012Metric_Pad1.20x1.40mm_HandSolder | ~
21 | 1 | RV1 | R_POT | PBLE-Circuit-rescue:R_POT-Device | Biblioteca PCB:P160KN-0QC15B100K
22 | 6 | SW1, SW2, SW3, SW4, SW5, SW_RESET1 | 1825910-6 | PBLE Library:1825910-6 | Button_Switch_THT:SW_TH_Tactile_Omron_B3F-10xx |  | 1825910-6 | Single Pole - Single Throw | 50 mA | Compliant
23 | 1 | U_A1 | LD1117S50TR_SOT223 | Regulator_Linear:LD1117S50TR_SOT223 | Package_TO_SOT_SMD:SOT-223-3_TabPin2 | http://www.st.com/st-web-ui/static/active/en/resource/technical/document/datasheet/CD00000544.pdf
24 | 1 | U_AMP5 | LM324DG | PBLE Library:LM324DG | Biblioteca PCB:LM324DG
25 | 1 | U_LCD1 | LCD2X16 | PBLE Library:LCD2X16 | Biblioteca PCB:JHD162A |  |  |  |  |  | Microelektronika | 10mm | 0 | Manufacturer Recommendations
26 | 1 | U_PIC18F4450 | PIC18F4550-IPT | MCU_Microchip_PIC18:PIC18F4550-IPT | Package_QFP:TQFP-44_10x10mm_P0.8mm | http://ww1.microchip.com/downloads/en/DeviceDoc/39760d.pdf
27 | 1 | U_RTC5 | MCP7940N-xSN | PBLE-Circuit-rescue:MCP7940N-xSN-Timer | Biblioteca PCB:MCP7940N | http://ww1.microchip.com/downloads/en/DeviceDoc/20005010F.pdf
28 | 1 | U_USB_SERIAL_CONVERSOR1 | MCP2200-I-SO | Interface_USB:MCP2200-I-SO | Package_SO:SOIC-20W_7.5x12.8mm_P1.27mm | http://ww1.microchip.com/downloads/en/DeviceDoc/200022228D.pdf
29 | 1 | VR2 | 3296W-1-103RLF | PBLE Library:3296W-1-103RLF | Potentiometer_THT:Potentiometer_Bourns_3296W_Vertical |  |  |  |  |  | Bourns |  | 05/16 | Manufacturer Recommendation
30 | 1 | X_PIC1 | ATS20A | PBLE Library:ATS20A | Biblioteca PCB:ATS20A
31 | 1 | X_RTC5 | AB38T-32.768KHZ | PBLE Library:AB38T-32.768KHZ | Biblioteca PCB:AB38T |  |  |  |  |  | Abracon Corparation |  | 12.29.14 | IPC-7251
32 | 1 | X_USB1 | ATS12A | PBLE Library:ATS12A | Biblioteca PCB:ATS12A

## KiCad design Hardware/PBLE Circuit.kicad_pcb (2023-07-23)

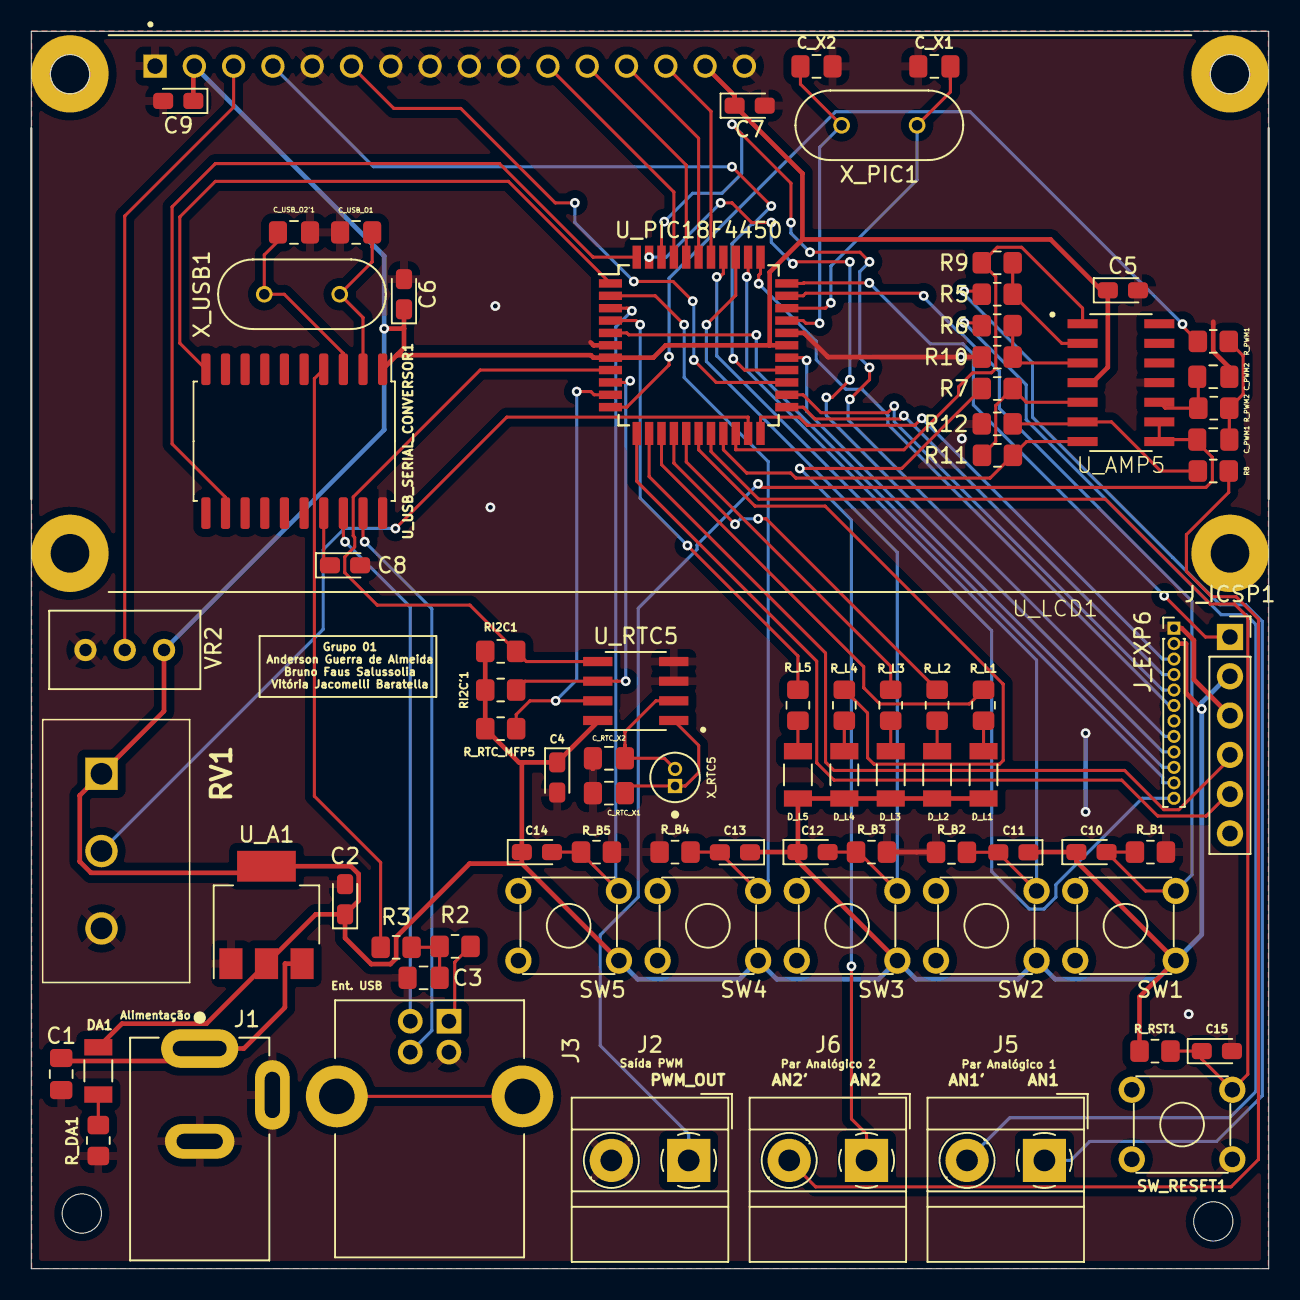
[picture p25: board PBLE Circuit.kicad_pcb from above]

Board: 2 copper layers, 80.0 x 80.0 mm, 80 parts (0 on the bottom side), 71 nets.

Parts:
C1: 100n; C_0805_2012Metric_Pad1.18x1.45mm_HandSolder
C2, C4, C5, C6, C7, C8, C9, C10, C11, C12, C13, C14, C15: 10u; CP_EIA-2012-15_AVX-P_Pad1.30x1.05mm_HandSolder
C3: 100nF; C_0805_2012Metric_Pad1.18x1.45mm_HandSolder
C_PWM1: 20p; C_0805_2012Metric_Pad1.18x1.45mm_HandSolder
C_PWM2: 39p; C_0805_2012Metric_Pad1.18x1.45mm_HandSolder
C_RTC_X1, C_RTC_X2: 22pF; C_0805_2012Metric_Pad1.18x1.45mm_HandSolder
C_USB_O1, C_USB_O2'1: 22pF; C_0805_2012Metric_Pad1.18x1.45mm_HandSolder
C_X1, C_X2: 15pF; C_0805_2012Metric_Pad1.18x1.45mm_HandSolder
DA1: LED; LTST-C150GKT
D_L1, D_L2, D_L3, D_L4, D_L5: LED; LTST-C150GKT
J1: PJ-002A; CUI_PJ-002A
J2, J5, J6: Screw_Terminal_01x02; TerminalBlock_MetzConnect_Type011_RT05502HBWC_1x02_P5.00mm_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
J3: USB_B; USB_B_Lumberg_2411_02_Horizontal
J_EXP6: Conn_01x12_Male; PinHeader_1x12_P1.00mm_Vertical
J_ICSP1: Conn_01x06; PinSocket_1x06_P2.54mm_Vertical
R2, R5, R6, R7, R8: 10k; R_0805_2012Metric_Pad1.20x1.40mm_HandSolder
R3: 470; R_0805_2012Metric_Pad1.20x1.40mm_HandSolder
R9, R10, R11, R12: 2k4; R_0805_2012Metric_Pad1.20x1.40mm_HandSolder
RI2C1, RI2C'1: 4k7; R_0805_2012Metric_Pad1.20x1.40mm_HandSolder
RV1: R_POT; P160KN-0QC15B100K
R_B1, R_B2, R_B3, R_B4, R_B5: 4k7; R_0805_2012Metric_Pad1.20x1.40mm_HandSolder
R_DA1: 330; R_0805_2012Metric_Pad1.20x1.40mm_HandSolder
R_L1, R_L2, R_L3, R_L4, R_L5: 4k7; R_0805_2012Metric_Pad1.20x1.40mm_HandSolder
R_PWM1, R_PWM2: 20k; R_0805_2012Metric_Pad1.20x1.40mm_HandSolder
R_RST1: 4k7; R_0805_2012Metric_Pad1.20x1.40mm_HandSolder
R_RTC_MFP5: 10k; R_0805_2012Metric_Pad1.20x1.40mm_HandSolder
SW1, SW2, SW3, SW4, SW5: 1825910-6; SW_TH_Tactile_Omron_B3F-10xx
SW_RESET1: 1825910-6; SW_TH_Tactile_Omron_B3F-10xx
U_A1: LD1117S50TR_SOT223; SOT-223-3_TabPin2
U_AMP5: LM324DG
U_LCD1: LCD2X16; JHD162A
U_PIC18F4450: PIC18F4550-IPT; TQFP-44_10x10mm_P0.8mm
U_RTC5: MCP7940N-xSN; MCP7940N
U_USB_SERIAL_CONVERSOR1: MCP2200-I-SO; SOIC-20W_7.5x12.8mm_P1.27mm
VR2: 3296W-1-103RLF; Potentiometer_Bourns_3296W_Vertical
X_PIC1: ATS20A
X_RTC5: AB38T-32.768KHZ; AB38T
X_USB1: ATS12A

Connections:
+5V: C2.1, C4.1, C5.1, C6.1, C7.1, C9.1, C10.1, C11.1, C12.1, C13.1, C14.1, DA1.2 (A), D_L1.2 (A), D_L2.2 (A), D_L3.2 (A), D_L4.2 (A), D_L5.2 (A), J_EXP6.2, J_ICSP1.2, RI2C1.1, RI2C'1.1, RV1.1, R_RST1.1, R_RTC_MFP5.2, SW1.1, SW2.1, SW3.1, SW4.1, SW5.1, U_A1.2 (VO), U_AMP5.4 (VCC), U_LCD1.2 (VDD), U_LCD1.15 (LEDA), U_PIC18F4450.7 (VDD), U_PIC18F4450.28 (VDD), U_RTC5.8 (VCC), U_USB_SERIAL_CONVERSOR1.1 (VDD), VR2.3
/Alimentação/D+: J3.3 (D+), U_USB_SERIAL_CONVERSOR1.19 (D+)
/Alimentação/D-: J3.2 (D-), U_USB_SERIAL_CONVERSOR1.18 (D-)
/Alimentação/MCP_RST: R3.1, U_USB_SERIAL_CONVERSOR1.4 (RST)
/Interação com o usuário/B1: C10.2, R_B1.2, SW1.3, U_PIC18F4450.32 (T1OSO/T13CKI/RC0)
/Interação com o usuário/B2: C11.2, R_B2.2, SW2.3, U_PIC18F4450.35 (~UOE/CCP2/T1OSI/RC1)
/Interação com o usuário/B3: C12.2, R_B3.2, SW3.3, U_PIC18F4450.36 (P1A/CCP1/RC2)
/Interação com o usuário/B4: C13.2, R_B4.2, SW4.3, U_PIC18F4450.2 (SPP4/RD4)
/Interação com o usuário/B5: C14.2, R_B5.2, SW5.3, U_PIC18F4450.3 (P1B/SPP5/RD5)
/Interação com o usuário/L1: R_L1.1, U_PIC18F4450.14 (RB4/AN11/KBI0/CSSPP)
/Interação com o usuário/L2: R_L2.1, U_PIC18F4450.15 (RB5/KBI1/PGM)
/Interação com o usuário/L3: R_L3.1, U_PIC18F4450.16 (RB6/KBI2/PGC)
/Interação com o usuário/L4: R_L4.1, U_PIC18F4450.17 (RB7/KBI3/PGD)
/Interação com o usuário/L5: R_L5.1, U_PIC18F4450.4 (P1C/SPP6/RD6)
/Interação com o usuário/LCD.DB4: U_LCD1.11 (DB4), U_PIC18F4450.41 (SPP3/RD3)
/Interação com o usuário/LCD.DB5: U_LCD1.12 (DB5), U_PIC18F4450.40 (SPP2/RD2)
/Interação com o usuário/LCD.DB6: U_LCD1.13 (DB6), U_PIC18F4450.39 (SPP1/RD1)
/Interação com o usuário/LCD.DB7: U_LCD1.14 (DB7), U_PIC18F4450.38 (SPP0/RD0)
/Interação com o usuário/LCD.E: U_LCD1.6 (E), U_PIC18F4450.25 (CK1SPP/AN5/RE0)
/Interação com o usuário/LCD.RS: U_LCD1.4 (RS), U_PIC18F4450.26 (CK2SPP/AN6/RE1)
/Interação com o usuário/POT.OUT: RV1.2, U_PIC18F4450.21 (RA2/AN2/Vref-/CVref)
/Operação/AN1: R9.1, U_AMP5.1 (OUT1), U_PIC18F4450.20 (RA1/AN1)
/Operação/AN2: R11.1, U_AMP5.7 (OUT2), U_PIC18F4450.19 (RA0/AN0)
/Operação/ICPORTS: J_EXP6.6, U_PIC18F4450.34 ((ICPORTS))
/Operação/ICRST: J_ICSP1.1, U_PIC18F4450.33 ((~ICRST/ICVpp))
/Operação/MFP: R_RTC_MFP5.1, U_PIC18F4450.10 (RB2/AN8/INT2/VMO), U_RTC5.7 (MFP)
/Operação/PWM: R_PWM1.2, U_PIC18F4450.11 (RB3/AN9/CCP2/VPO)
/Operação/RA3: J_EXP6.3, U_PIC18F4450.22 (RA3/AN3/Vref+)
/Operação/RA4: J_EXP6.4, U_PIC18F4450.23 (RA4/T0CKI/C1OUT/RCV)
/Operação/RA5: J_EXP6.5, U_PIC18F4450.24 (RA5/AN4/~SS/HLVDIN/C2OUT)
/Operação/RC4: J_EXP6.8, U_PIC18F4450.42 (VM/D-/RC4)
/Operação/RC5: J_EXP6.9, U_PIC18F4450.43 (VP/D+/RC5)
/Operação/RD7: J_EXP6.11, U_PIC18F4450.5 (P1D/SPP7/RD7)
/Operação/RE2: J_EXP6.10, U_PIC18F4450.27 (OESPP/AN7/RE2)
/Operação/SCL: RI2C'1.2, U_PIC18F4450.9 (RB1/AN10/INT1/SCK/SCL), U_RTC5.6 (SCL)
/Operação/SDA: RI2C1.2, U_PIC18F4450.8 (RB0/AN12/INT0/FLT0/SDI/SDA), U_RTC5.5 (SDA)
/Operação/VUSB': J_EXP6.12, U_PIC18F4450.37 (VUSB)
AN1: J5.1, R5.2
AN1': J5.2, R6.2
AN2: J6.1, R7.2
AN2': J6.2, R8.2
A_IN+: R6.1, R10.2, U_AMP5.3 (IN1)
A_IN-: R5.1, R9.2, U_AMP5.2 (IN1)
B_IN+: R8.1, R12.2, U_AMP5.6 (IN2)
B_IN-: R7.1, R11.2, U_AMP5.5 (IN2)
CLK0: C_X1.1, U_PIC18F4450.31 (RA6/OSC2/CLKO), X_PIC1.1
CLK1: C_X2.1, U_PIC18F4450.30 (OSC1/CLKI), X_PIC1.2
C_IN+: C_PWM2.2, R_PWM2.1, U_AMP5.10 (IN3)
GNDREF: C1.2, C2.2, C3.1, C4.2, C5.2, C6.2, C7.2, C8.2, C9.2, C15.2, C_PWM2.1, C_RTC_X1.2, C_RTC_X2.2, C_USB_O1.2, C_USB_O2'1.2, C_X1.2, C_X2.2, J1.2, J1.3, J2.2, J3.4 (GND), J_EXP6.1, J_ICSP1.3, R10.1, R12.1, RV1.3, R_B1.1, R_B2.1, R_B3.1, R_B4.1, R_B5.1, R_DA1.2, SW_RESET1.1, U_A1.1 (GND), U_AMP5.11 (VEE,_GND), U_LCD1.1 (VSS), U_LCD1.5 (R/W), U_LCD1.7 (DB0), U_LCD1.8 (DB1), U_LCD1.9 (DB2), U_LCD1.10 (DB3), U_LCD1.16 (LEDK), U_PIC18F4450.6 (VSS), U_PIC18F4450.29 (VSS), U_RTC5.3 (VBAT), U_RTC5.4 (VSS), U_USB_SERIAL_CONVERSOR1.20 (VSS), VR2.1
MCLR: C15.1, R_RST1.2, SW_RESET1.3, U_PIC18F4450.18 (Vpp/~MCLR/RE3)
unnamed: C3.2, R2.1, R3.2
unnamed: C8.1, U_USB_SERIAL_CONVERSOR1.17 (V_USB)
unnamed: C_PWM1.1, R_PWM1.1, R_PWM2.2
unnamed: DA1.1 (K), R_DA1.1
unnamed: D_L1.1 (K), R_L1.2
unnamed: D_L2.1 (K), R_L2.2
unnamed: D_L3.1 (K), R_L3.2
unnamed: D_L4.1 (K), R_L4.2
unnamed: D_L5.1 (K), R_L5.2
unnamed: J3.1 (VBUS), R2.2
unnamed: U_LCD1.3 (VO), VR2.2
PGC: J_ICSP1.5, U_PIC18F4450.12 ((ICCK/ICPGC))
PGD: J_ICSP1.4, U_PIC18F4450.13 ((ICDT/ICPGD))
PWM_OUT: C_PWM1.2, J2.1, U_AMP5.8 (OUT3), U_AMP5.9 (IN3)
USB.O1: C_USB_O1.1, U_USB_SERIAL_CONVERSOR1.2 (OSC1), X_USB1.1
USB.O2: C_USB_O2'1.1, U_USB_SERIAL_CONVERSOR1.3 (OSC2), X_USB1.2
USB.RX: U_PIC18F4450.44 (TX/CK/RC6), U_USB_SERIAL_CONVERSOR1.12 (RX)
USB.TX: U_PIC18F4450.1 (SDO/RX/DT/RC7), U_USB_SERIAL_CONVERSOR1.10 (TX)
VCC: C1.1, J1.1, U_A1.3 (VI)
X1: C_RTC_X1.1, U_RTC5.1 (X1), X_RTC5.1
X2: C_RTC_X2.1, U_RTC5.2 (X2), X_RTC5.2

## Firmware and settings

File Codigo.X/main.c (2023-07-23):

/*
 * File:   main.c
 * Author: João Luiz de Miranda Cilli
 *
 * Created on 27 de Março de 2023, 14:01
 */

#include"event.h"
#include"var.h"
#include"stateMachine.h"
#include"output.h"
#include"timer.h"

void main(void){
    //Inicializações
    timerInit();
    varInit();
    eventInit();
    outputInit();
    smInit();
    for (;;) {
        timerReset(getTime());
        smLoop();//máquina de estados 
        timerWait();
    }
}

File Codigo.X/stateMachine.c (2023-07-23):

#include "var.h"
#include "stateMachine.h"
#include "event.h"
#include "output.h"
#include "lcd.h"
#include "button.h"
#include "adc.h"
#include "led.h"


void smInit(void) {
    //Estado Inicial
    setState(STATE_TEMPO);
    adcInit();
    ledInit();
}

void smLoop(void) {
    unsigned char evento;

    //Máquina de estados
    
    evento = eventRead();
    
    //Verifica se valores estão maiores ou menos que os máximos e mínimos permitidos
    
    if(adcRead(1)>getAlarmLevel1a()){
        ledState(0,1);
    }else{
        ledState(0,0);
    }
    
    if(adcRead(3)>getAlarmLevel2a()){
        ledState(2,1);
    }else{
        ledState(2,0);
    }
    
    if(adcRead(1)<getAlarmLevel1b()){
        ledState(1,1);
    }else{
        ledState(1,0);
    }
    
    if(adcRead(3)<getAlarmLevel2b()){
        ledState(3,1);
    }else{
        ledState(3,0);
    }
        
    //Execução dos Eventos
      
    switch (getState()) {
        case STATE_ALARME_TEMP_MAX:
            //execução de atividade
            if (evento == EV_RIGHT) {
                setAlarmLevel1a(getAlarmLevel1a() + 1);
            }
            if (evento == EV_LEFT) {
                setAlarmLevel1a(getAlarmLevel1a() - 1);
            }

            //gestão da maquina de estado
            if (evento == EV_ENTER) {
                setState(STATE_ALARME_TEMP_MIN);
            }
            break;
        case STATE_ALARME_PRESS_MAX:
            //Execução de atividade
            if (evento == EV_RIGHT) {
                setAlarmLevel2a(getAlarmLevel2a() + 1);
            }
            if (evento == EV_LEFT) {
                setAlarmLevel2a(getAlarmLevel2a() - 1);
            }

            //Gestão da maquina de estado
            if (evento == EV_ENTER) {
                setState(STATE_ALARME_PRESS_MIN);
            }
            break;
        case STATE_ALARME_TEMP_MIN:
            //Execução de atividade
            if (evento == EV_RIGHT) {
                setAlarmLevel1b(getAlarmLevel1b() + 1);
            }
            if (evento == EV_LEFT) {
                setAlarmLevel1b(getAlarmLevel1b() - 1);
            }

            //Gestão da maquina de estado
            if (evento == EV_ENTER) {
                setState(STATE_ALARME_PRESS_MAX);
            }
            break;
        case STATE_ALARME_PRESS_MIN:
            //Execução de atividade
            if (evento == EV_RIGHT) {
                setAlarmLevel2b(getAlarmLevel2b() + 1);
            }
            if (evento == EV_LEFT) {
                setAlarmLevel2b(getAlarmLevel2b() - 1);
            }

            //Gestão da maquina de estado
            if (evento == EV_ENTER) {
                setState(STATE_TEMPO);
            }
            break;
        case STATE_TEMPO:

            //Execução de atividade
            if (evento == EV_RIGHT) {
                setTime(getTime() + 1);
            }
            if (evento == EV_LEFT) {
                setTime(getTime() - 1);
            }

            //Gestão da maquina de estado
            if (evento == EV_ENTER) {
                setState(STATE_IDIOMA);
            }
            break;

        case STATE_IDIOMA:

            //Execução de atividade
            if (evento == EV_RIGHT) {
                setLanguage(getLanguage() + 1);
            }
            if (evento == EV_LEFT) {
                setLanguage(getLanguage() - 1);
            }

            //Gestão da maquina de estado
            if (evento == EV_ENTER) {
                setState(STATE_ALARME_TEMP_MAX);
            }
            break;

    }
    //Feedback para o usuário
    outputPrint(getState(), getLanguage());
}
